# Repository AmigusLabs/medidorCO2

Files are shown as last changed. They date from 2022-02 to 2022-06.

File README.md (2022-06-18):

# Medidor CO<sub>2</sub> Maker
Aparato de medida de CO<sub>2</sub> para combatir la pandemia COVID-19.

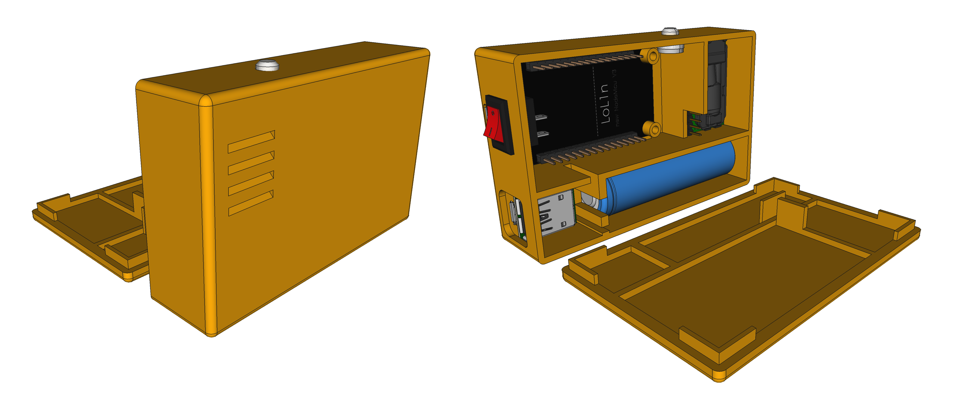
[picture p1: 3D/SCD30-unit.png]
MedidorCO2


Proyecto **Open-Source** y **Open-Hardware** (consulta la [licencia](#licencia--license)).

* **[Presentación](presentacion/):** información, objetivos, justificación y materiales ([ver *on-line*](https://mgesteiro.github.io/medidorCO2/)).
* **[Montaje](montaje/):** esquema de pines y conexionado.
* **[3D](3D/):** carcasa diseñada en [FreeCAD](https://freecadweb.org) lista para imprimir y montar.
* **[Código](codigo/):** para el *NodeMCU Lolin v3* usando el IDE de Arduino.

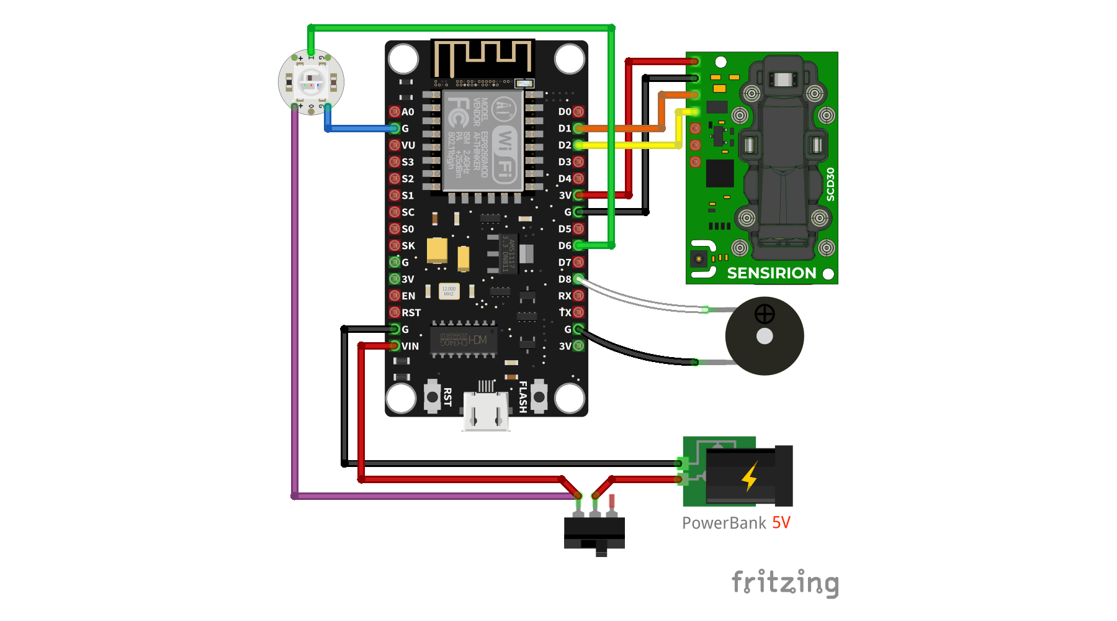
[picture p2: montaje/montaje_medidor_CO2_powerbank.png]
Montaje


## Alimentación eléctrica
El aparato se alimenta mediante un **PowerBANK-DIY adaptado** (tal y como se explica en [esta guía](https://www.roboteach.es/modificacion-power-bank/)) que encaja perfectamente en la carcasa.

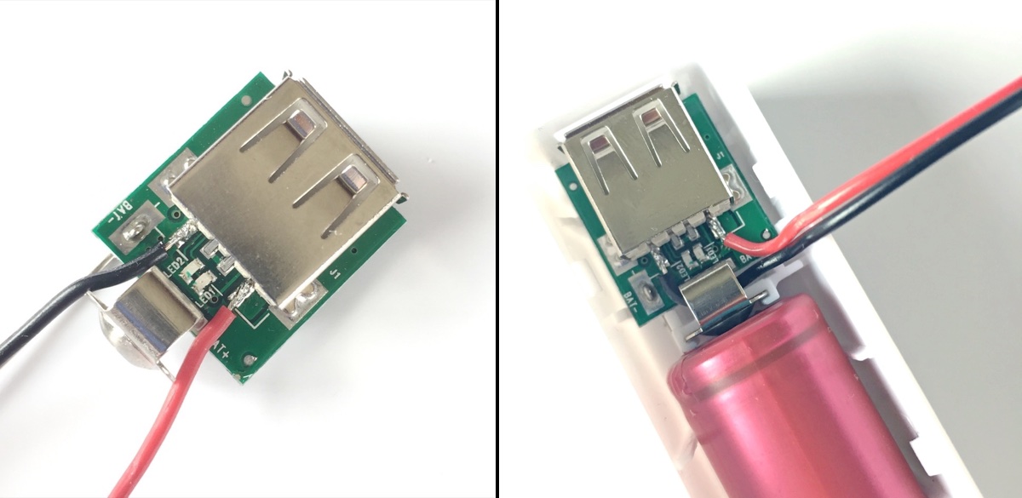
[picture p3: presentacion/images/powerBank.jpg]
PowerBANK


## Listado de materiales

* 1x Sensor CO2, temperatura y humedad tipo NDIR: Sensirion SCD30
* 1x NodeMCU Lolin v3
* 1x Buzzer activo 5V
* 1x Neopixel individual con pines
* 11x Cables dupont 10 cm hembra-hembra
* 1x Interruptor (Rocker switch)
* 1x PowerBank DIY
* 1x Batería 18650
* 1x Carcasa 3D impresa para contener el kit

## LICENCIA / LICENSE

Este trabajo esta sujeto a la licencia [GNU General Public v3.0 License](LICENSE-GPLV30). Todos los ficheros multimedia y de datos que no sean código fuente están sujetos a la licencia [Creative Commons Attribution 4.0 BY-SA license](LICENSE-CCBYSA40).

Más información acerca de estas licencias en [licencias Opensource](https://opensource.org/licenses/) y [licencias Creative Commons](https://creativecommons.org/licenses/).

This work is licensed under the [GNU General Public License v3.0](LICENSE-GPLV30). All media and data files that are not source code are licensed under the [Creative Commons Attribution 4.0 BY-SA license](LICENSE-CCBYSA40).

More information about licenses in [Opensource licenses](https://opensource.org/licenses/) and [Creative Commons licenses](https://creativecommons.org/licenses/).

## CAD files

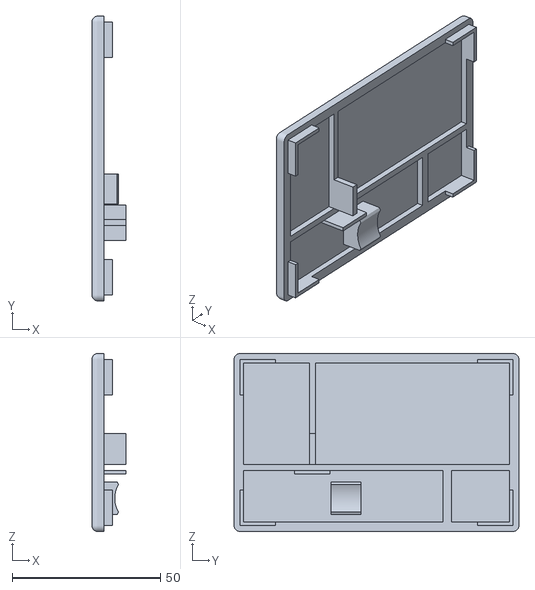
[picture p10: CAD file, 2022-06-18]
3D/SCD30-unit-cover.stl
11.5 x 96.0 x 60.0

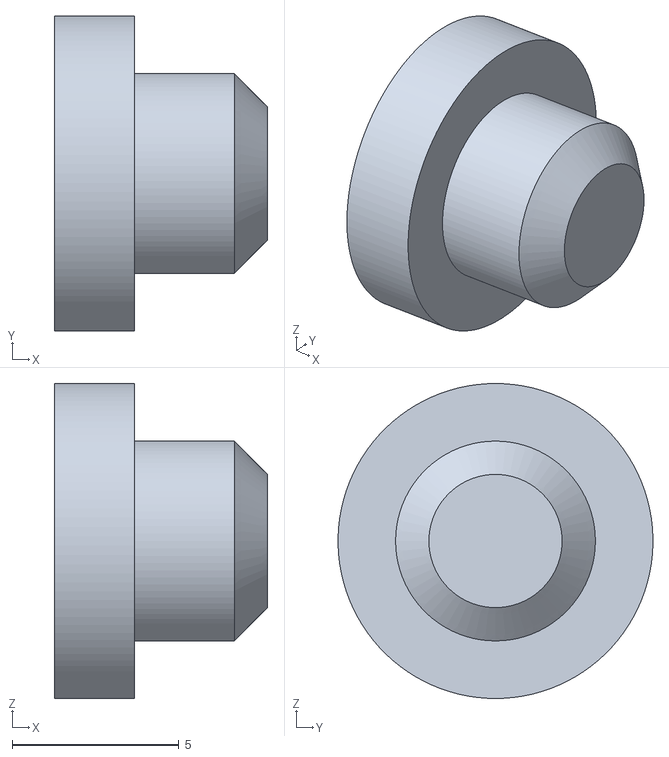
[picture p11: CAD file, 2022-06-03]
3D/SCD30-RGB-cap.stl
6.40 x 9.45 x 9.46

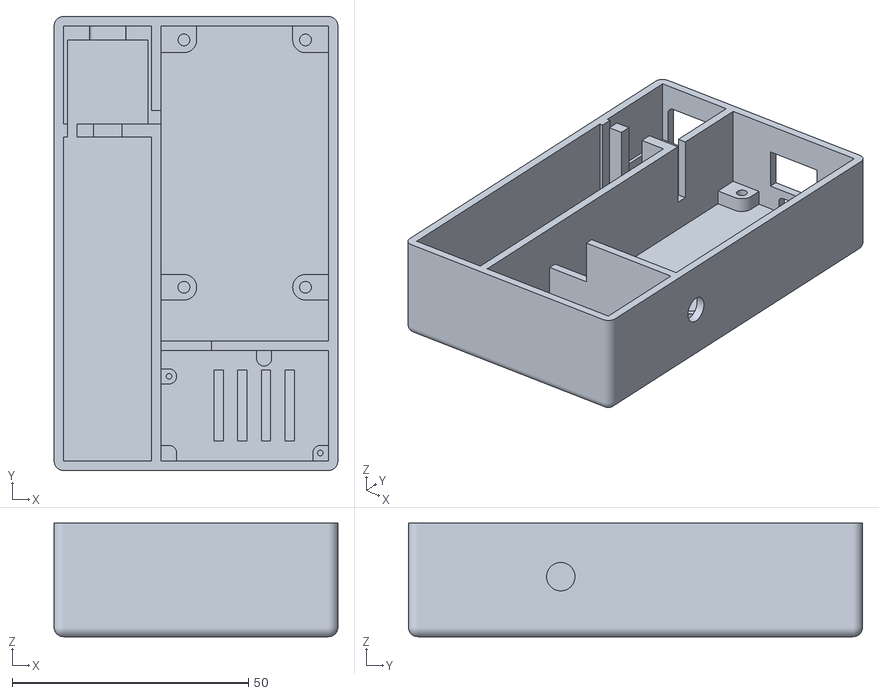
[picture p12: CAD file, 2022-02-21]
3D/SCD30-unit.stl
60.0 x 96.0 x 24.0

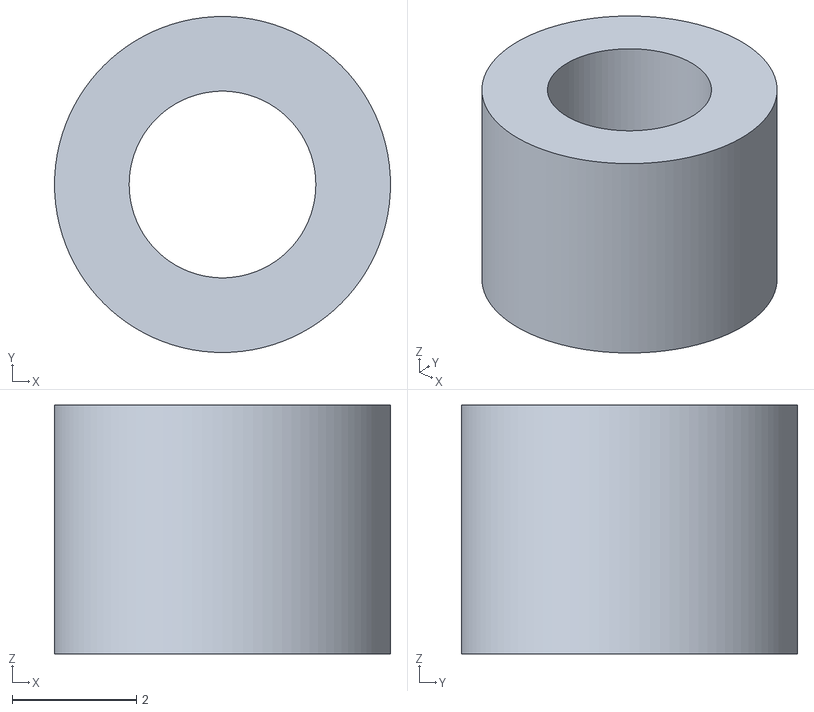
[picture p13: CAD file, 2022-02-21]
3D/SCD30-spacer.stl
5.40 x 5.40 x 4.00

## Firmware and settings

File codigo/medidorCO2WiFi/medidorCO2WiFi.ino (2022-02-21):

/*
 * Aparato de medición CO2
 * 
 * WiFi "CO2Sensor" (sin clave)
 * http://192.168.4.1
 * 
 */

#include <ESP8266WiFi.h>
#include <WiFiClient.h>
#include <ESP8266WebServer.h>

// Sensor SDC30
#include <Wire.h>
#include "SparkFun_SCD30_Arduino_Library.h"
SCD30 airSensor;

// Neopixel
#include <Adafruit_NeoPixel.h>
#define PIN       D6
#define NUMPIXELS 1

Adafruit_NeoPixel pixels(NUMPIXELS, PIN, NEO_GRB + NEO_KHZ800);

const char *ssid = "CO2Sensor";

ESP8266WebServer server(80);

#define BUZZER D8

int nivelCO2_ideal=700;
int nivelCO2_peligro=800;
uint16_t  nivelCO2;
float temperatura, humedad;
long tiempo, tCO2=0, talarma=0;
bool alarma=false;

/*
 * Devuelve los valores numéricos en una página HTML
 */
void handleRoot() {
  // Respuesta web
  char respuesta[250];
  sprintf(respuesta, "<html><head><title>Sensor CO2</title><meta http-equiv=\"refresh\" content=\"2\" /></head><body style=\"font-size:200%%;\">Nivel CO2(ppm): %d<br>Temperatura(C): %.1f<br>Humedad(%%): %.1f</body></html>", nivelCO2, temperatura, humedad);

  server.send(200, "text/html", respuesta);
} // handleRoot()


void setup() {
  pinMode(BUZZER, OUTPUT);
  delay(2000); // darle tiempo al sensor
  Serial.begin(115200);
  Serial.println();
  Serial.println("Inicializando medidor CO2 wifi ...");

  Wire.begin();

  if (airSensor.begin() == false) {
    Serial.println("Sensor no detectado: por favor comprueba el conexionado. Sistema detenido.");
    while (1);
  }

  pixels.begin(); // Inicializar NeoPixel
  pixels.clear(); // Todos los pixel sin color (= 0,0,0)
  pixels.show();  // Mostramos
  
  // arrancamos wifi
  WiFi.softAP(ssid);

  // indicamos nuestra propia IP por el puerto serie
  IPAddress myIP = WiFi.softAPIP();
  Serial.print("Entra en http://");
  Serial.println(myIP);
  
  // servimos la página web
  server.on("/", handleRoot);
  server.begin();
  Serial.println("Servidor web iniciado");
}

void loop() {
  // atendemos las peticiones web
  server.handleClient();

  // eventos temporizados
  tiempo=millis();

  // Buzzer (pita una vez cada segundo si estamos en zona roja)
  if(alarma==true) {
    if ((tiempo-talarma)>1000) talarma=tiempo;

    if((tiempo-talarma)<100) digitalWrite(BUZZER, HIGH);
    else digitalWrite(BUZZER, LOW);
  }

  // Medida de CO2
  if ((tiempo-tCO2)<2000) return;
  
  tCO2=tiempo;
  
  if (airSensor.dataAvailable()) {
    nivelCO2=airSensor.getCO2();
    temperatura=airSensor.getTemperature();
    humedad=airSensor.getHumidity();
  
    // Los indicamos por el puerto serie también
    Serial.print("CO2(ppm): ");
    Serial.print(nivelCO2);
    Serial.print(" Temperatura(C): ");
    Serial.print(temperatura, 1);
    Serial.print(" Humedad(%): ");
    Serial.println(humedad, 1);
    
    if (nivelCO2<=nivelCO2_ideal) {
      pixels.setPixelColor(0, pixels.Color(0, 127, 0)); // Color VERDE
      pixels.show();
      alarma=false;
      digitalWrite(BUZZER, LOW); // por si estaba encendido
    }
    if (nivelCO2>nivelCO2_ideal && nivelCO2<nivelCO2_peligro) {
      pixels.setPixelColor(0, pixels.Color(127, 50, 0)); // Color NARANJA
      pixels.show(); 
      alarma=false;
      digitalWrite(BUZZER, LOW); // por si estaba encendido
    }
    if (nivelCO2>=nivelCO2_peligro) {
      pixels.setPixelColor(0, pixels.Color(127, 0, 0)); // Color ROJO
      pixels.show();
      alarma=true;
    }
  } else {
    Serial.println("Esperando nuevos datos ...");
  }
}

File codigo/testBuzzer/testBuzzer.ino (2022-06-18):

/*
 * Test para el zumbador activo
 * OJO: ¡vigila la polaridad!
 */

// Buzzer
#define PIN  D8
 
void setup() {
   pinMode(PIN, OUTPUT);
}

void loop() {
  digitalWrite(PIN, HIGH);   // enciende el zumbador
  delay(1000);               // espera 1 segundo
  digitalWrite(PIN, LOW);    // apaga el zumbador
  delay(1000);               // espera 1 segundo
}

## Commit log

2022-02-21 Initial release
    [SCD30-spacer.stl, SCD30-unit.stl, montaje_medidor_CO2.fzz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]
2022-02-21 Bugfix: Comparacións cos umbrales
    Se nivelCO2 é exactamente igual que nivelCO2_peligro, non se cumple ningunha condicións
    [medidorCO2WiFi.ino]
2022-02-21 Updated connections and fix by lmiranda
    [montaje_medidor_CO2_powerbank.fzz]
2022-02-27 Added cover and NeoPixel test
    [SCD30-RGB-cap.stl, SCD30-unit-cover.stl]
2022-03-02 Added BOM
2022-06-18 Updated box cover, new buzzer test and some minor cosmetic changes.
    [SCD30-unit-cover.stl, montaje_medidor_CO2_powerbank.fzz]
